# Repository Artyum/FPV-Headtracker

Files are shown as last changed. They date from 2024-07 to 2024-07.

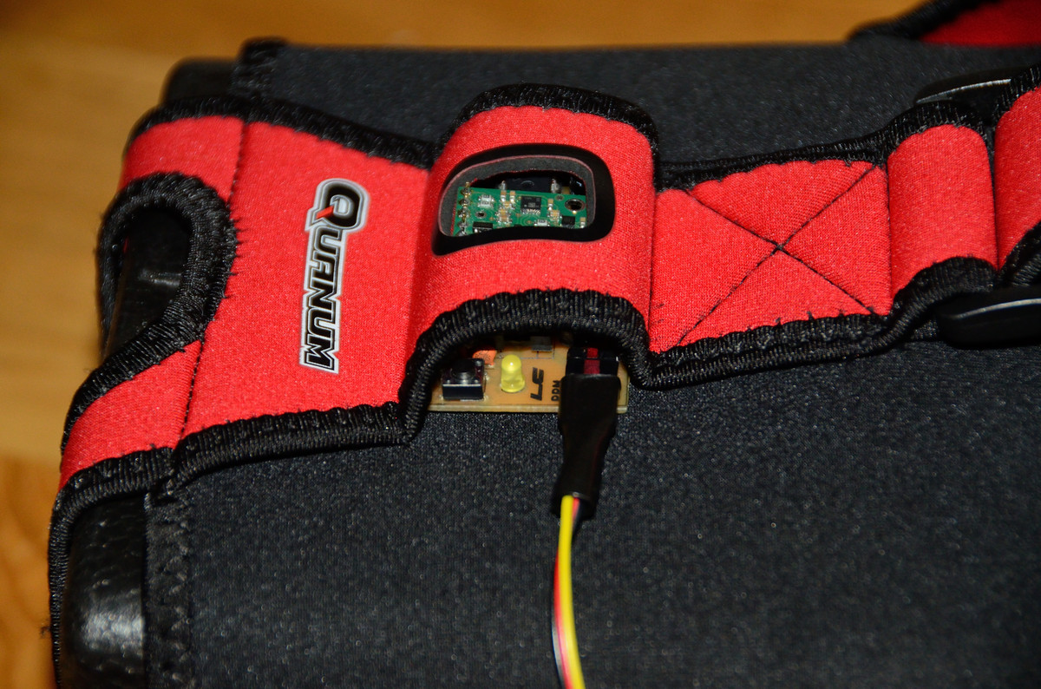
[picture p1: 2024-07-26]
Images/DSC_3236.JPG

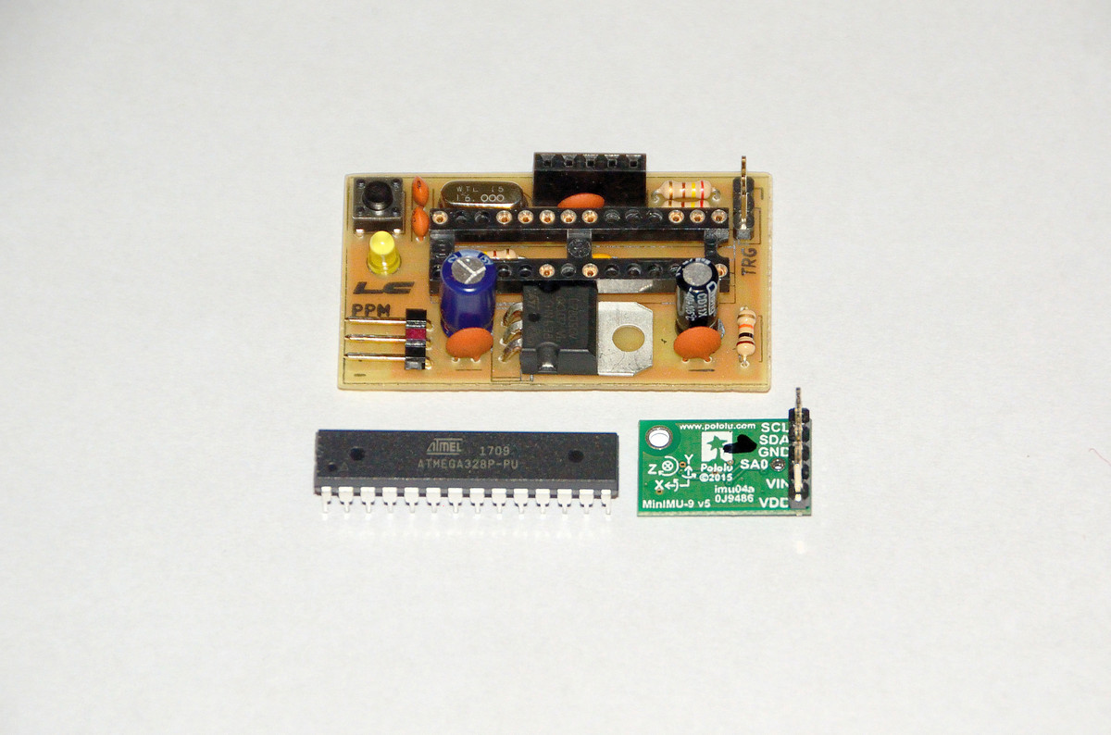
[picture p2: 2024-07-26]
Images/DSC_3263.JPG

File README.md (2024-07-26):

## FPH Headtracker for RC Airplanes

The FPH Headtracker is an advanced device designed for RC airplane enthusiasts. It enables pilots to control the camera on their RC aircraft by simply moving their head. This immersive technology enhances the flying experience by providing a first-person view (FPV) that moves naturally with the pilot's head movements. The headtracker system is equipped with sensors that accurately track the pilot's head position and transmit these movements to the camera gimbal on the RC airplane, allowing for precise and intuitive control. This innovation is particularly useful for aerial photography, racing, and immersive flight simulations, making the flying experience more engaging and realistic.



## Demonstration video
[MPX Mentor FPV with HEADTRACKER](https://www.youtube.com/watch?v=0JXXjhNscpw)

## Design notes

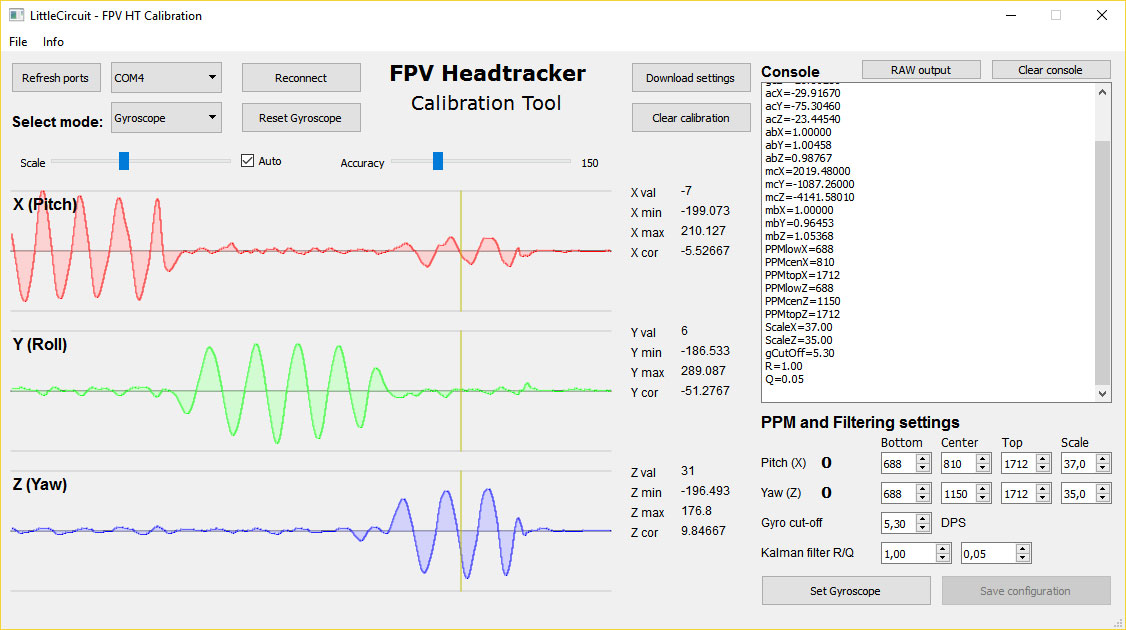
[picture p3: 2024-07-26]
Images/HTCalibTool.jpg

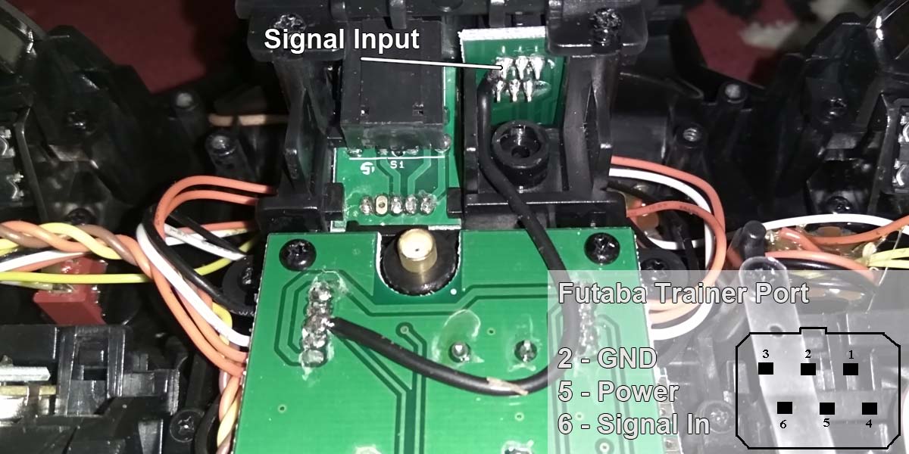
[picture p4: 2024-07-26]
Images/IMG-PPM.jpg

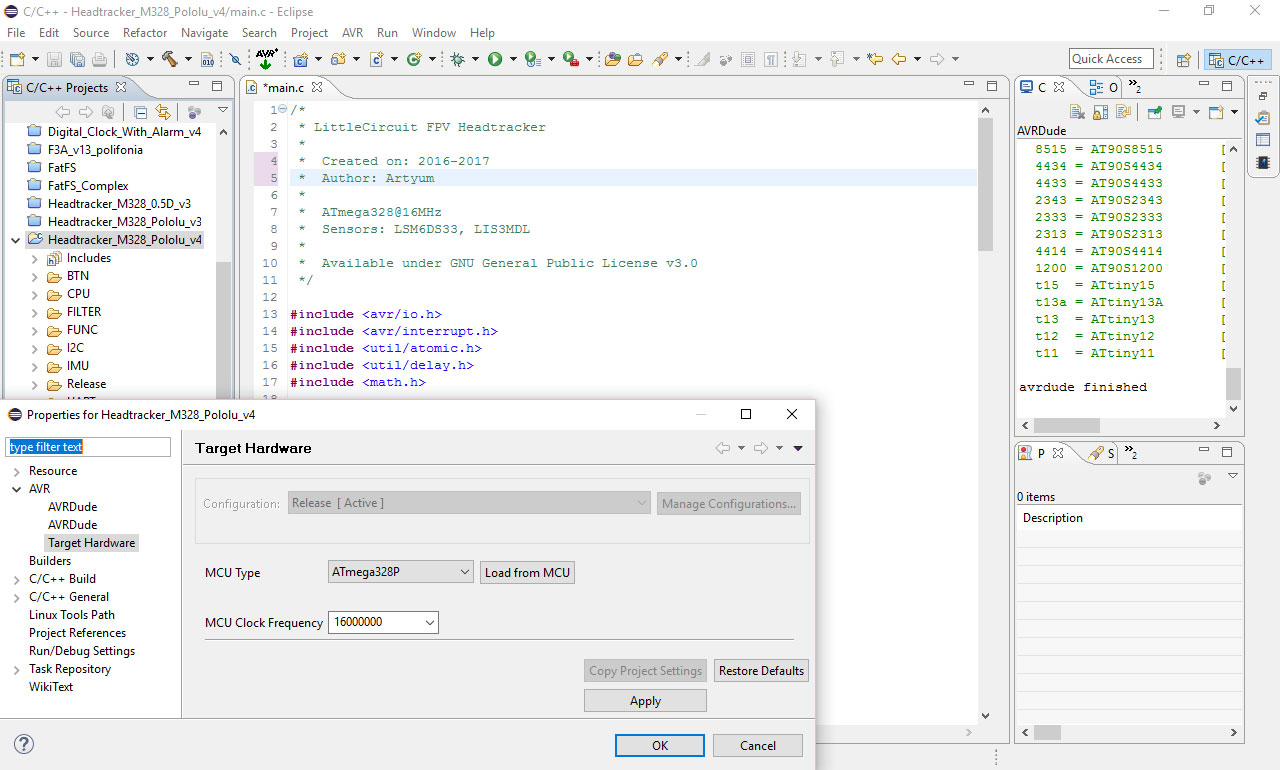
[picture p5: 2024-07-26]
Images/Eclipsescreen.jpg

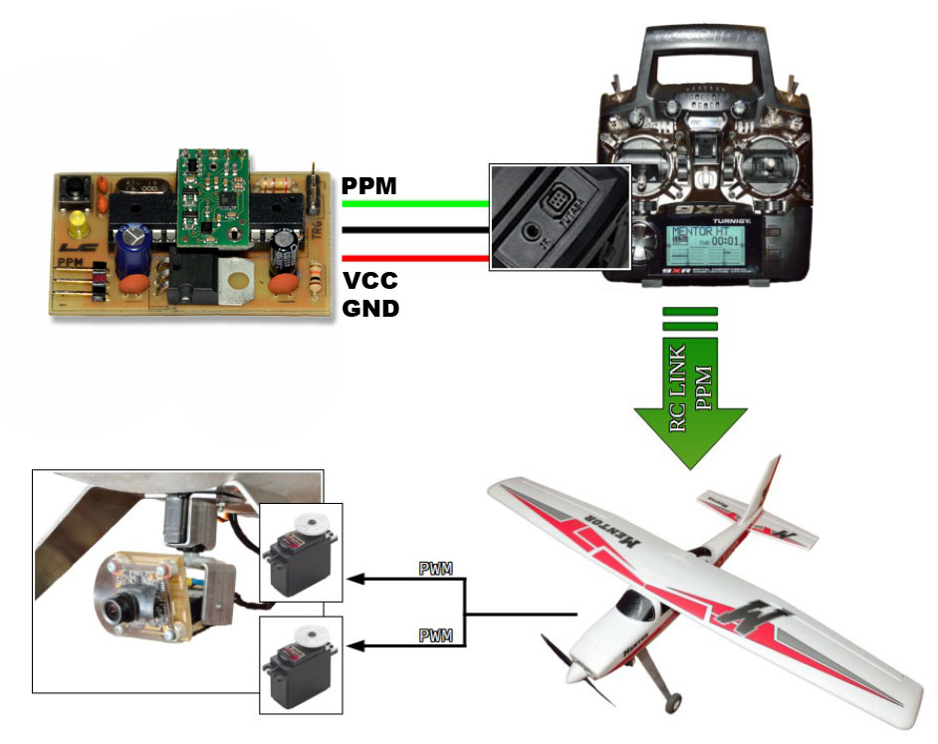
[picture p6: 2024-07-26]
Images/Schema.jpg

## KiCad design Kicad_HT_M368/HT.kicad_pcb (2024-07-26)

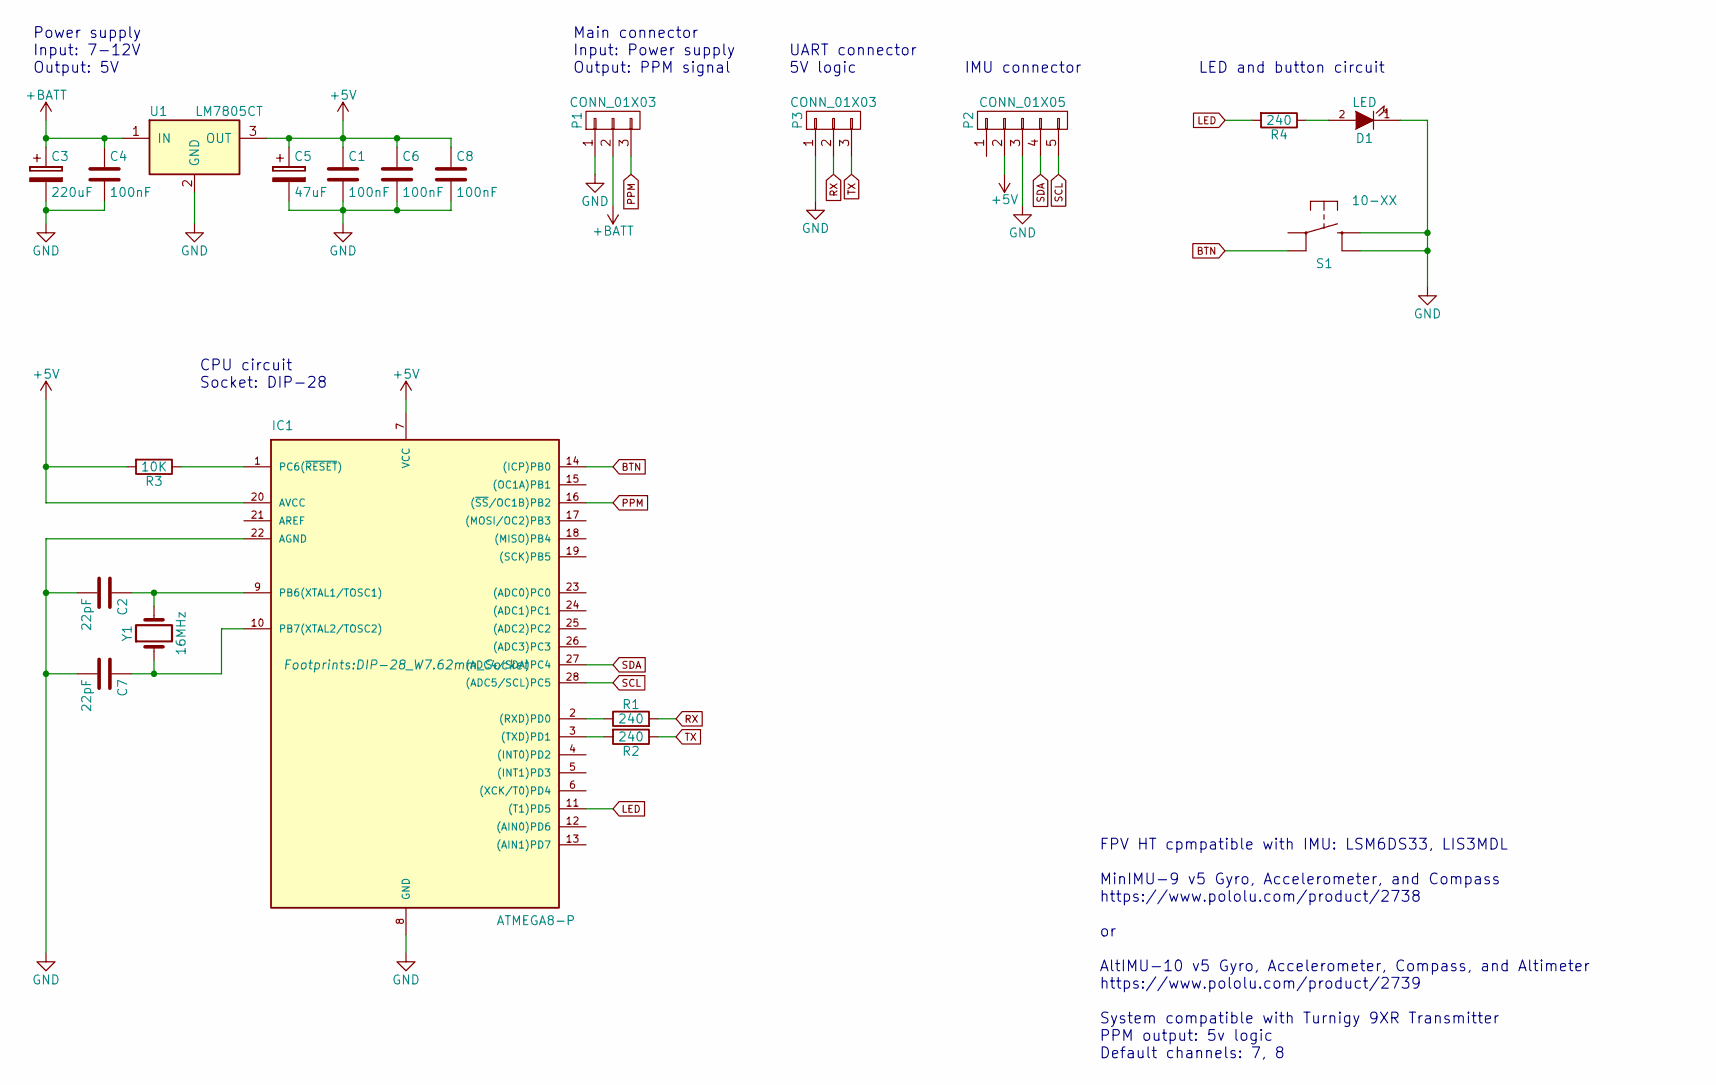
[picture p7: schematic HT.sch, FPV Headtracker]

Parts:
C1, C4, C6, C8: 100nF; C_Disc_D3_P2.5
C2, C7: 22pF; C_Disc_D3_P2.5
C3: 220uF; C_Radial_D5_L11_P2.5
C5: 47uF; C_Radial_D5_L11_P2.5
D1: LED; LED-3MM
IC1: ATMEGA8-P; DIP-28_W7.62mm_Socket
P1: CONN_01X03; Pin_Header_Angled_1x03
P2: CONN_01X05; Socket_Strip_Straight_1x05
P3: CONN_01X03; Pin_Header_Straight_1x03
R1, R2, R4: 240; R_Axial_DIN0207_L6.3mm_D2.5mm_P7.62mm_Horizontal
R3: 10K; R_Axial_DIN0207_L6.3mm_D2.5mm_P7.62mm_Horizontal
S1: 10-XX; B3F_10XX
U1: LM7805CT; TO-220_Horizontal
Y1: 16MHz; Crystal_HC49-4H_Vertical

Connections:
+5V: C1.1, C5.1, C6.1, C8.1, IC1.7 (VCC), IC1.20 (AVCC), P2.2, R3.2, U1.3 (OUT)
+BATT: C3.1, C4.1, P1.2, U1.1 (IN)
BTN: IC1.14 ((ICP)PB0), S1.4 (P1)
GND: C1.2, C2.2, C3.2, C4.2, C5.2, C6.2, C7.2, C8.2, D1.1 (K), IC1.8 (GND), IC1.22 (AGND), P1.1, P2.3, P3.1, S1.1 (S), S1.2 (S1), U1.2 (GND)
LED: IC1.11 ((T1)PD5), R4.2
unnamed: C2.1, IC1.9 (PB6(XTAL1/TOSC1)), Y1.2
unnamed: C7.1, IC1.10 (PB7(XTAL2/TOSC2)), Y1.1
unnamed: D1.2 (A), R4.1
unnamed: IC1.1 (PC6(~RESET~)), R3.1
unnamed: IC1.2 ((RXD)PD0), R1.1
unnamed: IC1.3 ((TXD)PD1), R2.2
PPM: IC1.16 ((~SS~/OC1B)PB2), P1.3
RX: P3.2, R1.2
SCL: IC1.28 ((ADC5/SCL)PC5), P2.5
SDA: IC1.27 ((ADC4/SDA)PC4), P2.4
TX: P3.3, R2.1

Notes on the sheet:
FPV HT cpmpatible with IMU: LSM6DS33, LIS3MDL MinIMU-9 v5 Gyro, Accelerometer, and Compass https://www.pololu.com/product/2738 or AltIMU-10 v5 Gyro, Accelerometer, Compass, and Altimeter https://www.pololu.com/product/2739 System compatible with Turnigy 9XR Transmitter PPM output: 5v logic Default 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
Power supply Input: 7-12V Output: 5V
Main connector Input: Power supply Output: PPM signal
UART connector 5V logic
IMU connector
LED and button circuit
CPU circuit Socket: DIP-28

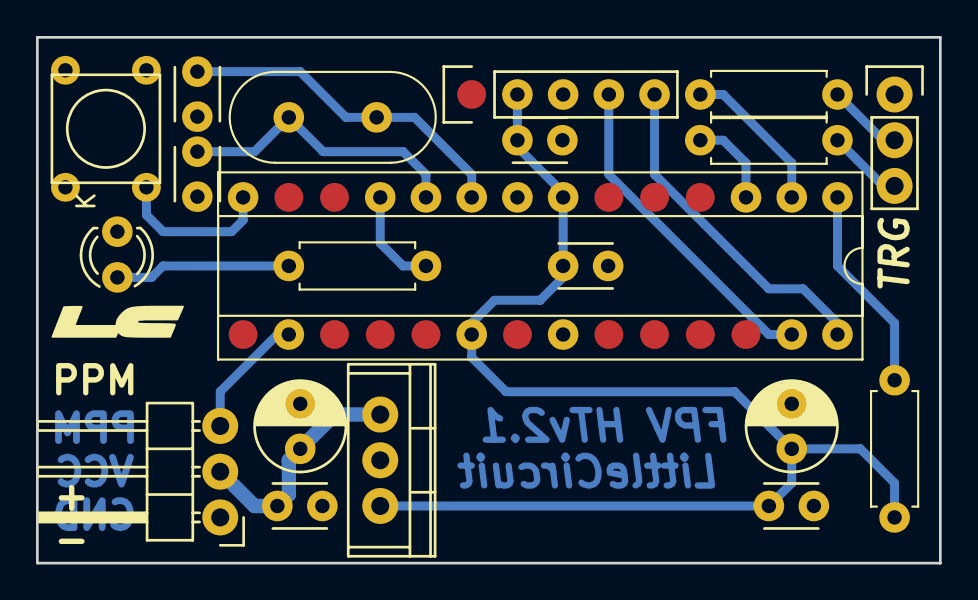
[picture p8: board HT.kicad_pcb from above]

Board: 2 copper layers, 50.2 x 29.2 mm, 20 parts (0 on the bottom side), 16 nets.

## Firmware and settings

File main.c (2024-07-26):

/*
 *  FPV Headtracker
 *
 *  Created on: 2016
 *
 * 	ATmega328@16MHz
 * 	Sensors: LSM6DS33, LIS3MDL
 */

#include <avr/io.h>
#include <avr/interrupt.h>
#include <util/atomic.h>
#include <util/delay.h>
#include <math.h>

#include "IMU/imu.h"
#include "FILTER/filter.h"
#include "BTN/btn.h"
#include "CPU/cpu.h"
#include "FUNC/func.h"
#include "I2C/i2c.h"
#include "UART/uart.h"

double xx, px, xz, pz;

int main(void) {
	//Initialization
	cpu_init();
	uart_init(UBRR_250000);
	i2c_init();
	imu_init();

	//Read calibration data
	readConfig();
	//sendConfig();

	//Setting default PPM channels length
	initPPM();

	//Initial position reset
	t_resetpos = POS_RESET_TIME;

	//Main loop
    while (1) {
		//Short press - Reset central position
		key_check(&btn_status, &t_btn, BTN_PINPORT, BTN_PIN);

		//Position reset
		if (btn_status==KEY_UP_SHORT) t_resetpos = POS_RESET_TIME;

		//Get from UART
		if (rxrdy) {
			if (rxbuf[0]=='E') calibtool = CALIB_IMU;
			if (rxbuf[0]=='F') calibtool = CALIB_PPM;
			if (rxbuf[0]=='C') sendConfig();
			if (rxbuf[0]=='S') saveConfig();
			if (rxbuf[0]=='G') resetGyro();
			if (rxbuf[0]=='A') resetAccel();
			if (rxbuf[0]=='M') resetMagnet();
			if (rxbuf[0]=='P') resetPPM();
			if (rxbuf[0]=='c') getConfig((char*)rxbuf);

			LED_ON; _delay_ms(50); LED_OFF;
			rxrdy = 0;
		}

		//Loop time
		uint16_t ms = t_ms;
		if ((ms>=5) && imuRdyGA()) {

			double dt = (double)ms/1000.0; //Delta t in seconds
			t_ms = 0;

			if (getGyro() && getAccel()) {
				corGyro();
				corAccel();

				//Get new magnetometer readings
				if (imuRdyM()) {
					getMagnet();
					corMagnet();
				}

				if (calibtool==CALIB_IMU) {
					uart_putc('#');
					for (uint8_t i=0; i<3; i++) { uart_putl(gft[i],10); uart_putc(';'); }
					for (uint8_t i=0; i<3; i++) { uart_putl(aft[i],10); uart_putc(';'); }
					for (uint8_t i=0; i<3; i++) { uart_putl(mft[i],10); uart_putc(';'); }
					uart_nl();
				}

				normGyro();
				normAccel();

				accPitch = calcPitch();
				accRoll = calcRoll();
				magYaw = calcYaw(accPitch, accRoll);
				//magAngleZ = kalman(yawTiltCompensation(accAngleX,accAngleY),&xz,&pz);

				//uart_putl(accRoll*R2D, 10); uart_puts("\t"); uart_putl(accPitch*R2D, 10); uart_puts("\t"); uart_putl(magYaw*R2D, 10); uart_nl();

				//Reset pozycji
				uint8_t rst = 0;
				if (t_resetpos) {
					rst = 1;
					LED_ON;

					accStartX = accPitch;
					magStartZ = magYaw;
				}

				accPitch = calcAbsAngle(accPitch, accStartX);
				magYaw = calcAbsAngle(magYaw, magStartZ);

				//uart_putl(accRoll*R2D, 10); uart_puts("\t"); uart_putl(accPitch*R2D, 10); uart_puts("\t"); uart_putl(magYaw*R2D, 10); uart_nl();
				//uart_putl(-gft[0],10); uart_puts("\t"); uart_putl(accRoll*R2D,10); uart_puts("\t"); uart_putl(-gft[2],10); uart_puts("\t"); uart_putl(magYaw*R2D,10); uart_nl();
				//uart_putl(gft[0],10); uart_puts("\t"); uart_putl(accRoll*R2D,10); uart_puts("\t"); uart_putd(dt,5); uart_nl();

				//Filter
				mergeAngles(&gyroAngleX, gft[0], accPitch, dt, rst);
				mergeAngles(&gyroAngleZ, gft[2], magYaw, dt, rst);

				//uart_putl(gyroAngleX,10); uart_puts("\t"); uart_putl(gyroAngleZ,10); uart_nl();

				//PPM generation
				newLenX = calcLenPPM(gyroAngleX, ppm_cen_x, ppm_low_x, ppm_top_x, ppm_scale_x);
				newLenZ = calcLenPPM(gyroAngleZ, ppm_cen_z, ppm_low_z, ppm_top_z, ppm_scale_z);

				//newLenX = kalman(calcLenPPM(gyroAngleX, ppm_cen_x, ppm_low_x, ppm_top_x, ppm_scale_x), &xx, &px);
				//newLenZ = kalman(calcLenPPM(gyroAngleZ, ppm_cen_z, ppm_low_z, ppm_top_z, ppm_scale_z), &xz, &pz);

				//uart_putl(gyroAngleX,10); uart_puts("\t");
				//uart_putl(ppm_cen_x,10); uart_puts("\t");
				//uart_putl(ppm_low_x,10); uart_puts("\t");
				//uart_putl(ppm_top_x,10); uart_puts("\t");
				//uart_putl(ppm_scale_x,10);uart_puts("\t");
				//uart_putl(newLenX/2,10); uart_nl();
				//uart_putl(newLenX/2,10); uart_puts("\t"); uart_putl(newLenZ/2,10); uart_nl();

				if (calibtool==CALIB_PPM) {
					uart_putc('%');
					uart_putl(newLenX/2,10); uart_putc(';');
					uart_putl(newLenZ/2,10);
					uart_nl();
				}

				//Final set PPM channels
				ATOMIC_BLOCK(ATOMIC_FORCEON) {
					ch_len[CH_ROLL] = newLenX;
					ch_len[CH_YAW] = newLenZ;
				}
			}
		}
		_delay_us(250);
	} //END while (1)

} //END main()

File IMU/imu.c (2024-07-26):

#include "imu.h"

double EEMEM egct[3]   = { 0.0, 0.0, 0.0 };		//gct[3]
uint8_t EEMEM eginv[3] = { 1, 1, 1 };			//ginv[3]

double EEMEM eact[3]   = { 0.0, 0.0, 0.0 };		//act[3]
double EEMEM eacn[3]   = { 1.0, 1.0, 1.0 };		//acn[3]
uint8_t EEMEM eainv[3] = { 1, 1, 1 };			//ainv[3]

double EEMEM emct[3]   = { 0.0, 0.0, 0.0 };		//mct[3]
double EEMEM emcn[3]   = { 1.0, 1.0, 1.0 };		//mcn[3]
uint8_t EEMEM eminv[3] = { 1, 1, 1 };			//minv[3]

//PPM settings

//Initial channels length
uint16_t EEMEM eppm_cen_x = CH_LEN_CNT;
uint16_t EEMEM eppm_cen_z = CH_LEN_CNT;

uint16_t EEMEM eppm_low_x = CH_LEN_MIN;
uint16_t EEMEM eppm_low_z = CH_LEN_MIN;
uint16_t EEMEM eppm_top_x = CH_LEN_MAX;
uint16_t EEMEM eppm_top_z = CH_LEN_MAX;

double EEMEM eppm_scale_x = PPM_SCALE_X;
double EEMEM eppm_scale_z = PPM_SCALE_Z;

double EEMEM egyro_cutoff = GYRO_CUTOFF;

double EEMEM ekal_r = KALMAN_R;
double EEMEM ekal_q = KALMAN_Q;

double gft[3];		//Gyro
double aft[3];		//Acc
double mft[3];		//Magnet

double gct[3];  	//Gryro correction
double act[3];		//Accel correction
double acn[3];		//Accel bias
double mct[3];		//Magnet correction
double mcn[3];		//Magnet bias

double gyro_cutoff;

void imu_init() {
	uint8_t r=1;

	//LSM6DS33
	if (!i2c_write_byte(I2C_ADDR_GA,	 GA_CTRL1_XL,		0b01001000)) r=0;	//Linear acceleration ODR 104Hz | +-4g | Anti-Aliasing 400Hz
	if (!i2c_write_byte(I2C_ADDR_GA,	 GA_CTRL2_G,		0b01001100)) r=0;	//Angular rate sensor ODR 104Hz | 2000 DPS
	if (!i2c_write_byte(I2C_ADDR_GA,	 GA_CTRL3_C,		0b01000100)) r=0;	//Output registers not updated until MSB and LSB have been read | Autoincrement | LSB @ lower address
	if (!i2c_write_byte(I2C_ADDR_GA,	 GA_CTRL4_C,		0b10000000)) r=0;	//XL_BW_SCAL_ORD=1 | SLEEP_G=0
	if (!i2c_write_byte(I2C_ADDR_GA,	 GA_CTRL5_C,		0b00000000)) r=0;
	if (!i2c_write_byte(I2C_ADDR_GA,	 GA_CTRL6_C,		0b00010000)) r=0;	//XL_HM_MODE=1 high-performance disabled
	if (!i2c_write_byte(I2C_ADDR_GA,	 GA_CTRL7_C,		0b10000000)) r=0;	//G_HM_MODE=1 high-performance disabled
	if (!i2c_write_byte(I2C_ADDR_GA,	 GA_CTRL8_XL,		0b00000000)) r=0;
	if (!i2c_write_byte(I2C_ADDR_GA,	 GA_CTRL9_XL,		0b00111000)) r=0;	//Linear acceleration X Y Z enabled (default)
	if (!i2c_write_byte(I2C_ADDR_GA,	 GA_CTRL10_C,		0b00111000)) r=0;	//Gyroscope X Y Z enabled (default)

	//LIS3MDL
	if (!i2c_write_byte(I2C_ADDR_M,		M_CTRL_REG1,		0b01111100)) r=0;	//High-performance mode | 80Hz | FAST_ODR=0
	//if (!i2c_write_byte(I2C_ADDR_M,	M_CTRL_REG1,		0b10011100)) r=0;	//Temp enabled | Low-performance mode | 80Hz | FAST_ODR=0
	if (!i2c_write_byte(I2C_ADDR_M,		M_CTRL_REG2,		0b00000000)) r=0;	//+/-4 gauss
	//if (!i2c_write_byte(I2C_ADDR_M,	M_CTRL_REG3,		0b00000001)) r=0;	//Single-conversion mode with 80Hz
	if (!i2c_write_byte(I2C_ADDR_M,		M_CTRL_REG3,		0b00000000)) r=0;	//Continuous-conversion mode
	//if (!i2c_write_byte(I2C_ADDR_M,	M_CTRL_REG4,		0b00000000)) r=0;	//Z-axis Low-performance mode
	//if (!i2c_write_byte(I2C_ADDR_M, 	M_CTRL_REG4,		0b00001000)) r=0;	//Z-axis High-performance mode
	if (!i2c_write_byte(I2C_ADDR_M, 	M_CTRL_REG4,		0b00001100)) r=0;	//Z-axis Ultra High-performance mode
	if (!i2c_write_byte(I2C_ADDR_M,		M_CTRL_REG5,		0b01000000)) r=0;	//Output registers not updated until MSB and LSB have been read

	//Self-test
	if (!r || !imuTestGA() || !imuTestM()) {
		uart_puts("IMU TEST ERR\r\n");
		while (1) _delay_ms(100);
	}
}

//Odczyt zmiennych z EEPROM
void readConfig() {
	for (uint8_t i=0; i<3; i++) {
		gct[i] = (double)eeprom_read_float((float *)&egct[i]);
		act[i] = (double)eeprom_read_float((float *)&eact[i]);
		acn[i] = (double)eeprom_read_float((float *)&eacn[i]);
		mct[i] = (double)eeprom_read_float((float *)&emct[i]);
		mcn[i] = (double)eeprom_read_float((float *)&emcn[i]);
	}
	ppm_cen_x = (uint16_t)eeprom_read_word((uint16_t *)&eppm_cen_x);
	ppm_cen_z = (uint16_t)eeprom_read_word((uint16_t *)&eppm_cen_z);
	ppm_low_x = (uint16_t)eeprom_read_word((uint16_t *)&eppm_low_x);
	ppm_low_z = (uint16_t)eeprom_read_word((uint16_t *)&eppm_low_z);
	ppm_top_x = (uint16_t)eeprom_read_word((uint16_t *)&eppm_top_x);
	ppm_top_z = (uint16_t)eeprom_read_word((uint16_t *)&eppm_top_z);
	ppm_scale_x = (double)eeprom_read_float((float *)&eppm_scale_x);
	ppm_scale_z = (double)eeprom_read_float((float *)&eppm_scale_z);
	gyro_cutoff = (double)eeprom_read_float((float *)&egyro_cutoff);
	kal_r = (double)eeprom_read_float((float *)&ekal_r);
	kal_q = (double)eeprom_read_float((float *)&ekal_q);
}

void saveConfig() {
	for (uint8_t i=0; i<3; i++) {
		eeprom_busy_wait(); eeprom_update_float((float *)&egct[i], gct[i]);
		eeprom_busy_wait(); eeprom_update_float((float *)&eact[i], act[i]);
		eeprom_busy_wait(); eeprom_update_float((float *)&eacn[i], acn[i]);
		eeprom_busy_wait(); eeprom_update_float((float *)&emct[i], mct[i]);
		eeprom_busy_wait(); eeprom_update_float((float *)&emcn[i], mcn[i]);
	}
	eeprom_busy_wait(); eeprom_update_word((uint16_t *)&eppm_cen_x, ppm_cen_x);
	eeprom_busy_wait(); eeprom_update_word((uint16_t *)&eppm_cen_z, ppm_cen_z);
	eeprom_busy_wait(); eeprom_update_word((uint16_t *)&eppm_low_x, ppm_low_x);
	eeprom_busy_wait(); eeprom_update_word((uint16_t *)&eppm_low_z, ppm_low_z);
	eeprom_busy_wait(); eeprom_update_word((uint16_t *)&eppm_top_x, ppm_top_x);
	eeprom_busy_wait(); eeprom_update_word((uint16_t *)&eppm_top_z, ppm_top_z);
	eeprom_busy_wait(); eeprom_update_float((float *)&eppm_scale_x, ppm_scale_x);
	eeprom_busy_wait(); eeprom_update_float((float *)&eppm_scale_z, ppm_scale_z);
	eeprom_busy_wait(); eeprom_update_float((float *)&egyro_cutoff, gyro_cutoff);
	eeprom_busy_wait(); eeprom_update_float((float *)&ekal_r, kal_r);
	eeprom_busy_wait(); eeprom_update_float((float *)&ekal_q, kal_q);
	uart_puts("$Save OK\r\n");
}

void initPPM() {
	for (uint8_t i=0; i<CH_NUMBER; i++) ch_len[i] = CH_LEN_CNT;
	ch_len[CH_ROLL] = ppm_cen_x;
	ch_len[CH_YAW] = ppm_cen_z;
	newLenX = ppm_cen_x;
	newLenZ = ppm_cen_z;
}
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
